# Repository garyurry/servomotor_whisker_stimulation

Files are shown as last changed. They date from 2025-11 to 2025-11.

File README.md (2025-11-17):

# servomotor_whisker_stimulator
A repository for an inexpensive, lab made servo motor setup for whisker stimulation of rodent whiskers. (for use with head-fixed experiments).
Make sure to read the Wiki for instructions for the whole project


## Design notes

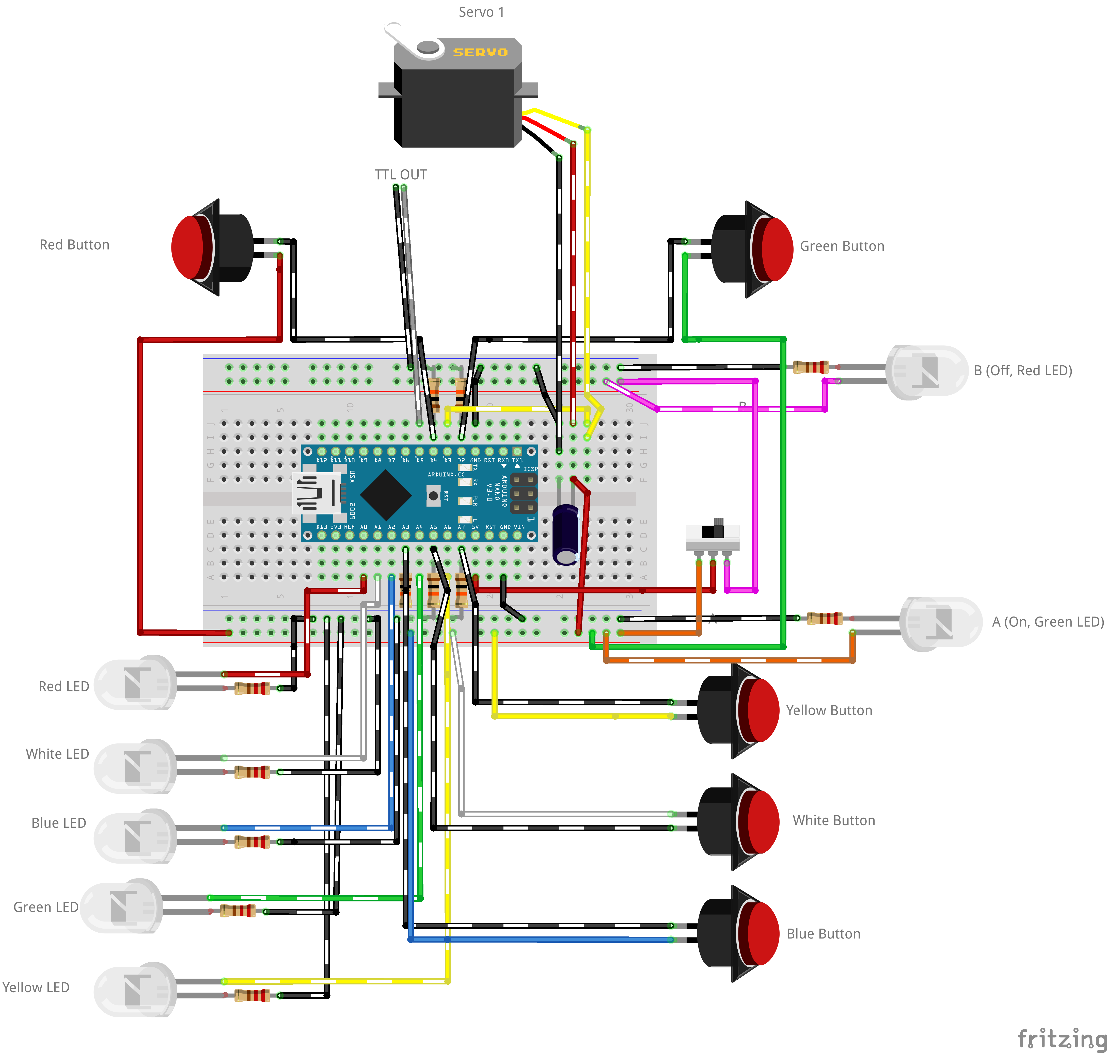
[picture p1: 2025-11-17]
WhiskerStim Servo Schematic.png

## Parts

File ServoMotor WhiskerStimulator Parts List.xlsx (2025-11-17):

Part | How Many Needed (per setup) | Link | Notes
Servo Motor (s) | 1 - 2 (package options from 2 pack to 8 pack) | Amazon.com: Miuzei MG90S 9G Micro Servo Motor Metal Geared Motor Kit for RC Car Robot Helicopter, Mini Servos for Arduino Project (5) : Toys & Games (https://www.amazon.com/Miuzei-Geared-Helicopter-Arduino-Project/dp/B0BWJ2CK9D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) | These servo motors have metal gears, making them more sturdy (able to handle paw-swipes from mice) - but any servo motor setup will work, just make sure you wire the servo correctly to the arduino
Arduino Nano | 1 | Arduino Nano Every with headers — Arduino Online Shop (https://store-usa.arduino.cc/products/nano-every-with-headers?pr_prod_strat=e5_desc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) | Any Arduino Nano can be used (ex. Nano Every, Arduino ESP 32, or any board that will fit in the housing)
BreadBoard (Permanent Soldered) | 1 | 723 Adafruit Industries LLC | Prototyping, Fabrication Products | DigiKey (https://www.digikey.com/en/products/detail/adafruit-industries-llc/723/6560937?gQT=1) | Arduino will fit on top of breadboard, and the included 3d printed holder has pegs to glue the breadboard onto the holder
LEDs | 1 Pack (has way more than needed but can be used for other projects) | Amazon.com: DiCUNO 120Pcs 12V Pre Wired 5MM Light Emitting Diodes, 9.4 Inch Ultra Bright LED Diodes (6 Colors×20Pcs) Assorted Color Kit Box for Circuit Science Experiment, DIY Lighting Projects : Industrial & Scientific (https://www.amazon.com/DiCUNO-Emitting-Assorted-Experiment-Lighting/dp/B0CYKXCJTW) | This is a pack of 10 x 6 colors of LEDs (10 pieces each of 6 different colors). They also include built-in resistors. Any LEDs you want can be used, but these come with longer wires that are easy to trim to size if needed.
Buttons | 1 Pack (more than needed, can use for other projects) | Twidec/12PCS 3V-6V-12V-24V-250V Momentary Push Button Switch 2 Pins ON/Off SPST 7mm 6 Colors Normal Open 1A Mini Round Button Switch with Pre-soldered Wires PBS-110-X6C: Amazon.com: Industrial & Scientific (https://www.amazon.com/Twidec-Colors-Momentary-Pre-soldered-PBS-110-X6C/dp/B07RTZVZ6L) | This pack has 12 pieces (you will only need 6). These buttons can be mounted on our included 3D printed holder
Toggle Switch | 1 (Pack has 10 pieces) | Gikfun MTS102 2 Position 3 Pins Mini Toggle Switch for Arduino (Pack of 10pcs) EK2021: Amazon.com: Industrial & Scientific (https://www.amazon.com/Gikfun-MTS102-Position-Toggle-Arduino/dp/B01BWL7Z44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) | This pack has 10 toggle switches, only 1 is needed - you can use whatever toggle switch you want
Spare Wire | (If Needed - use any spare wiring) | TUOFENG 22 awg Wire Solid Core Hookup Wires-6 Different Colored Breadboard Wires 30ft or 9m Each, 22 Gauge Electronic Wire PVC (OD: 1.60mm) Arduino Wires - Amazon.com (https://www.amazon.com/TUOFENG-Hookup-Wires-6-Different-Colored/dp/B07TX6BX47?s=industrial) | Spare wire spools if needed. Any spare wire can be used.
SMA Connector | 1 | Amazon.com: XMSJSIY SMA Male to Dupont Wire Coaxial Coax Test Leads Cable Connector Adapter Extension Wire (Red+Black)-1 pcs : Electronics (https://www.amazon.com/XMSJSIY-Coaxial-Connector-Adapter-Extension/dp/B09TBCHHDG?gQT=1) | For the TTL out signal if needed
Screws | 4 (optional) |  | Optional screws for the holder - the holder is designed to be press fit, but for extra support it includes screw holes. We used 6 - 20 x 1/2 self drilling screws (pan head)
Servo Motor Holder | 1 | 3D printer file (included .stl file "Servo Motor Mount) | Print in ABS or PETG - For use on laboratory mounting devices (will fit on a mounting system up to 14mm in diameter)
Glass Pipette Holder (Option for straight on and drop down) | 1 | 3D printer file (included .stl files | Print in any filament - meant to offer a press fit for glass pipettes, but can also use a small clamp to keep in place
Circuit Holder Bottom | 1 | 3D printer file (included .stl file "Servo Motor Mount) | Can be printed in any filament - Part where the circuit and breadboard are mounted
Circuit Holder Top (For Buttons and LEDs) | 1 | 3D printer file (included .stl file "Servo Motor Mount) | Can be printed in any filament - Part where the LEDs and Buttons are mounted

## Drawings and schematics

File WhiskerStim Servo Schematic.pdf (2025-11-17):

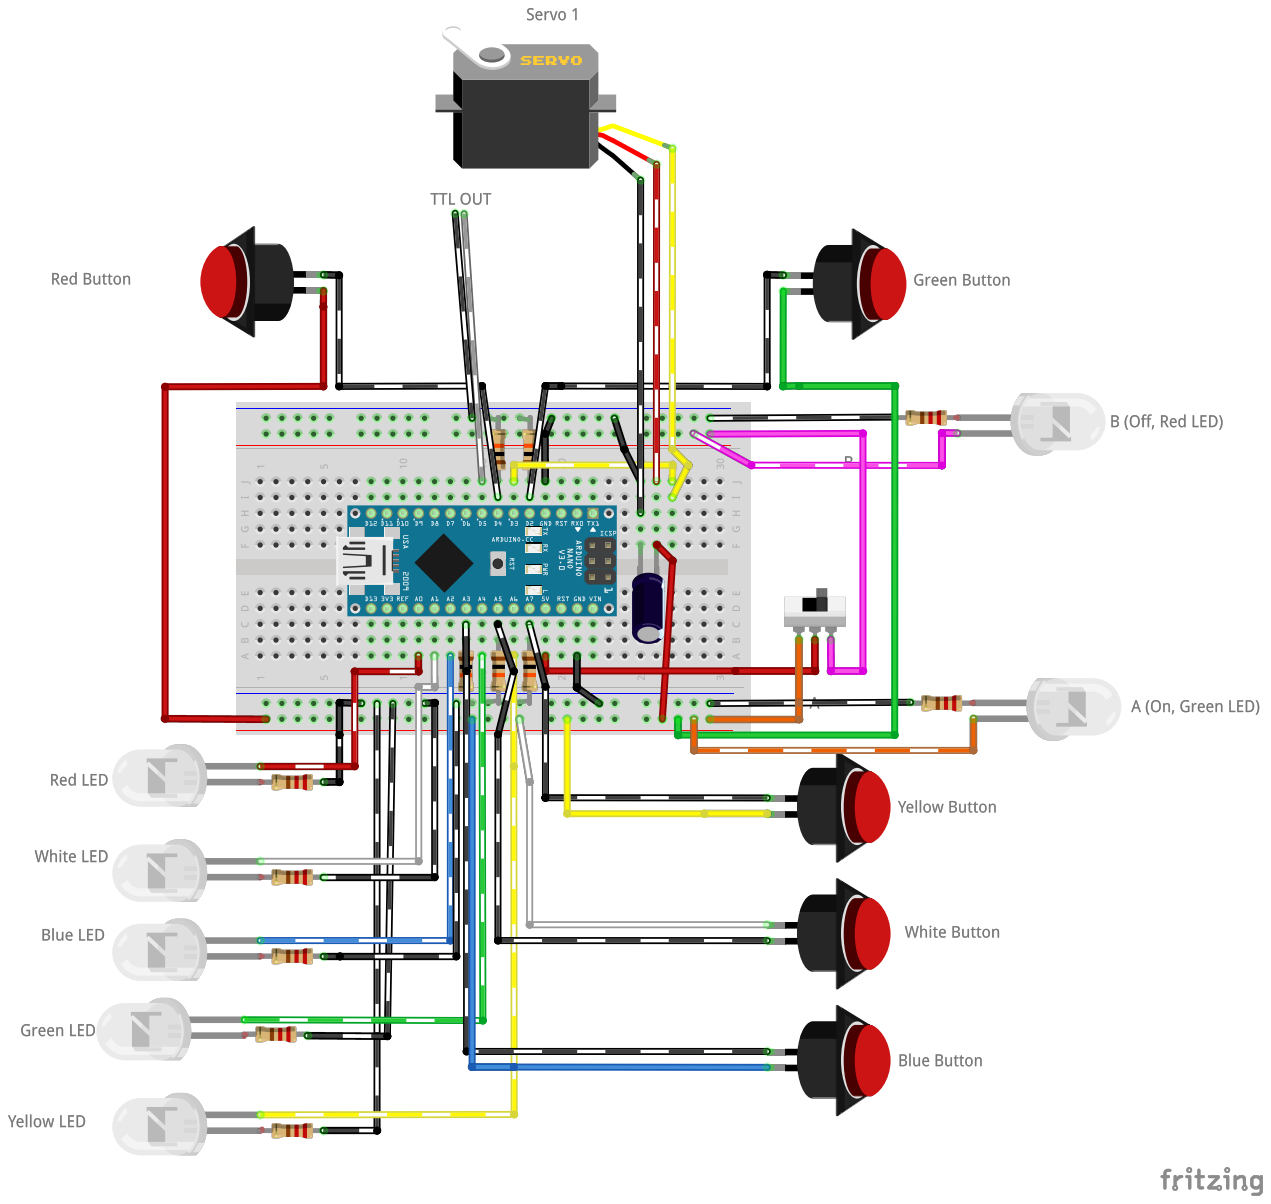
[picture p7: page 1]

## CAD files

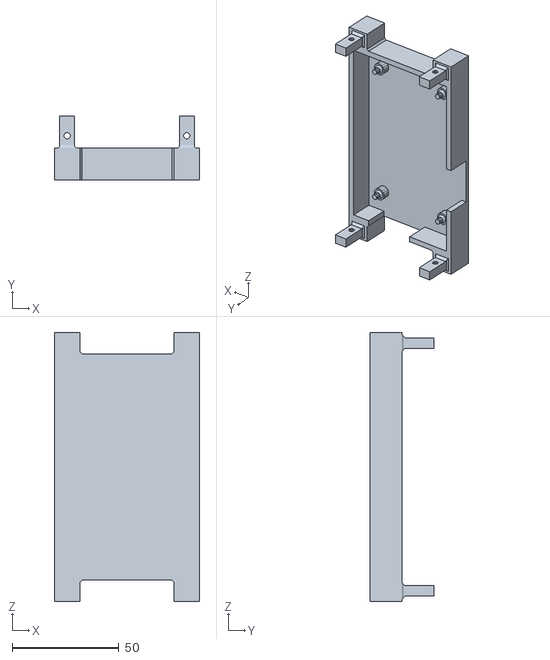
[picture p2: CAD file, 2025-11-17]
servo circuit holder github.stl
68.0 x 30.0 x 126.0

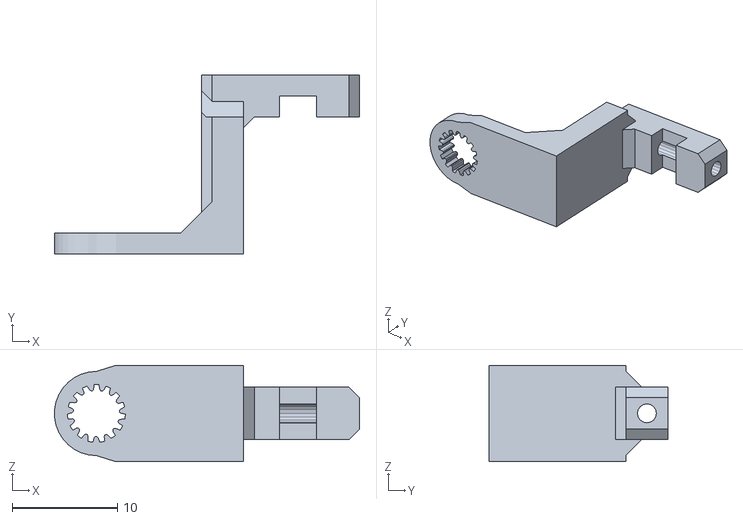
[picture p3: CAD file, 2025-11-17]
servo part pipette holder drop down github.stl
29.0 x 17.0 x 9.17

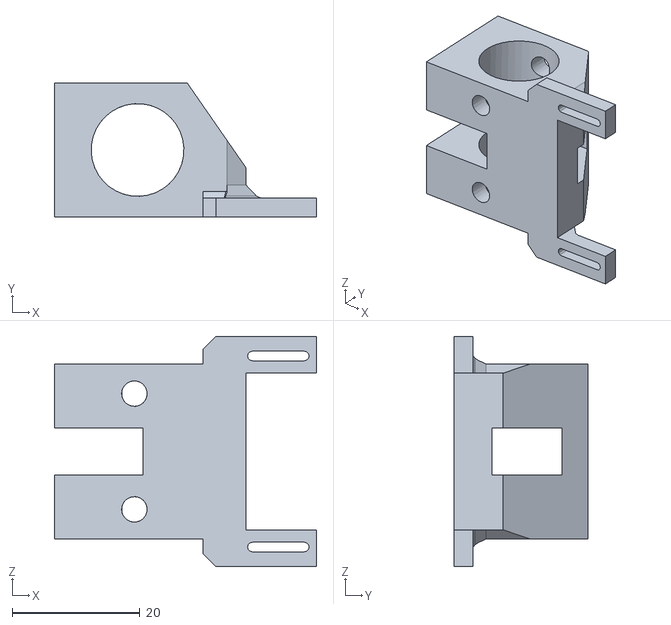
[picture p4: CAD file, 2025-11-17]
servo holder gitbub.stl
41.0 x 21.0 x 36.0

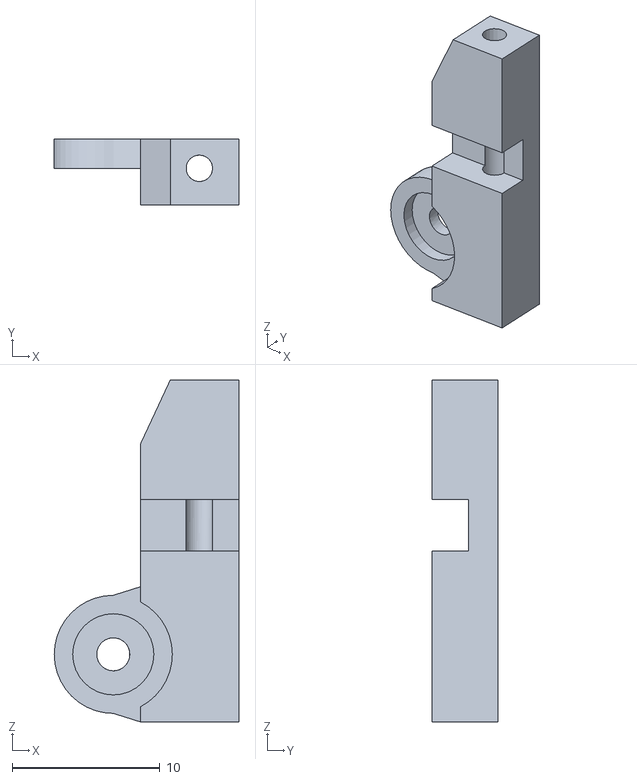
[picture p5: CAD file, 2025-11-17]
servo part pipette holder github.stl
12.5 x 4.50 x 23.2

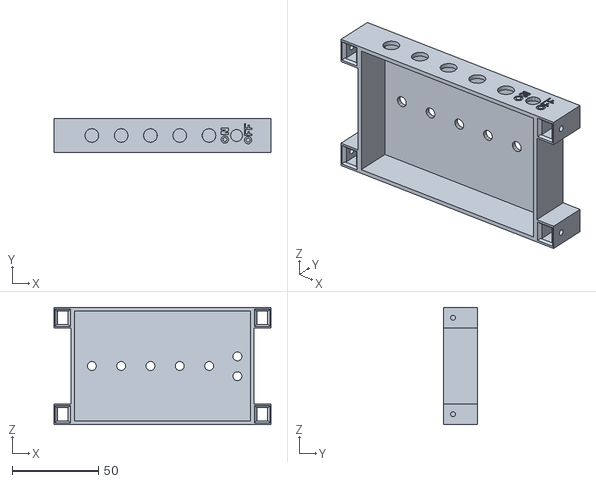
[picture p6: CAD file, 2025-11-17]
servo circuit holder top gitbhub.stl
126.0 x 20.0 x 68.0
